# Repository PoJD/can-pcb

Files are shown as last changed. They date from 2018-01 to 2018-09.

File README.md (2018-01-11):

# can-pcb
Custom PCBs to be used for CAN bus in my home automation project
This repository contains 2 separate Eagle projects (http://www.cadsoftusa.com/) for custom PCB designed by myself to allow home automation system work with CAN BUS.

The basic idee is that there are 2 projects:

1. CanRelay
2. CanSwitch

CanRelay is a PCB that will be directly connected to the SSR relays and will consume traffic over the CAN bus (from either the webapp - hawa - or from CanSwitch) and translate that to switching output pins on that board's chip on or off. The board chip is PIC18F25K80 and is programmed through either CanRelay.X or CanSwitch.X mplab projects here: https://github.com/PoJD/can

CanSwitch is a PCB that will be present in the wall and would have 1 single input for the input switch, 1 single output for an indicator LED and would be connected to the CAN network too and transfer the toggle switch CAN messages over the wire to the CanRelay PCB to process.

Followed https://www.sparkfun.com/tutorials/110 to create custom components bought for this PCB and resulting in a custom library here: https://github.com/PoJD/eagle
Then followed https://learn.sparkfun.com/tutorials/using-eagle-schematic/adding-parts-to-a-schematic and other related guides to create the PCB in Eagle application.

https://learn.sparkfun.com/tutorials/using-eagle-board-layout#generating-gerbers and http://www.allpcb.com/sns/Gerber+File/2017-02-24_1_10_4819_Create+a+Gerber+File+with+Eagle/rpllst.html for generating Gerber files to let the PCBs get manufactured

See details of the communication protocal in that project, this is simply a project designed to have custom boards that would then be installed in the house.

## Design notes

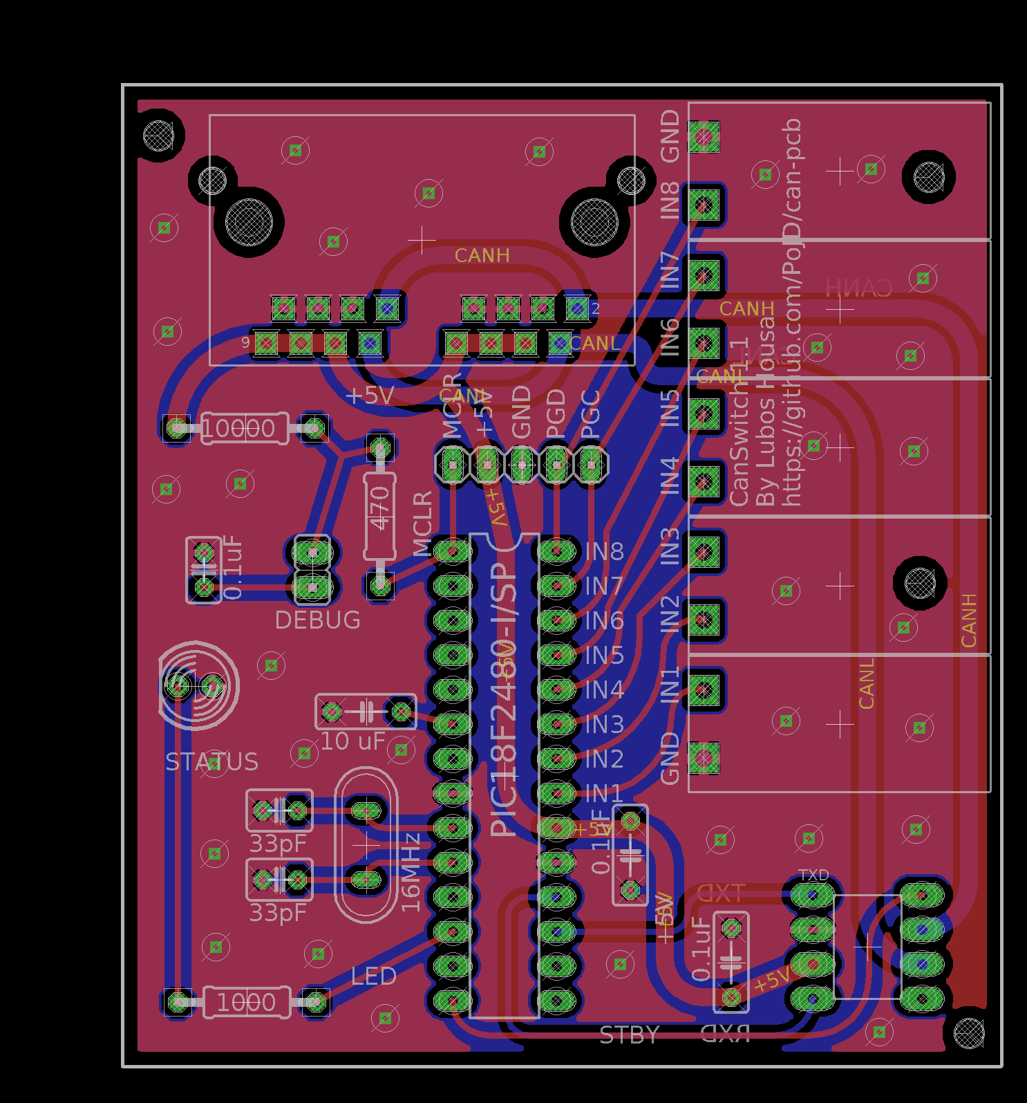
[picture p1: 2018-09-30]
Gerbers/CanSwitch/ImageExport.png

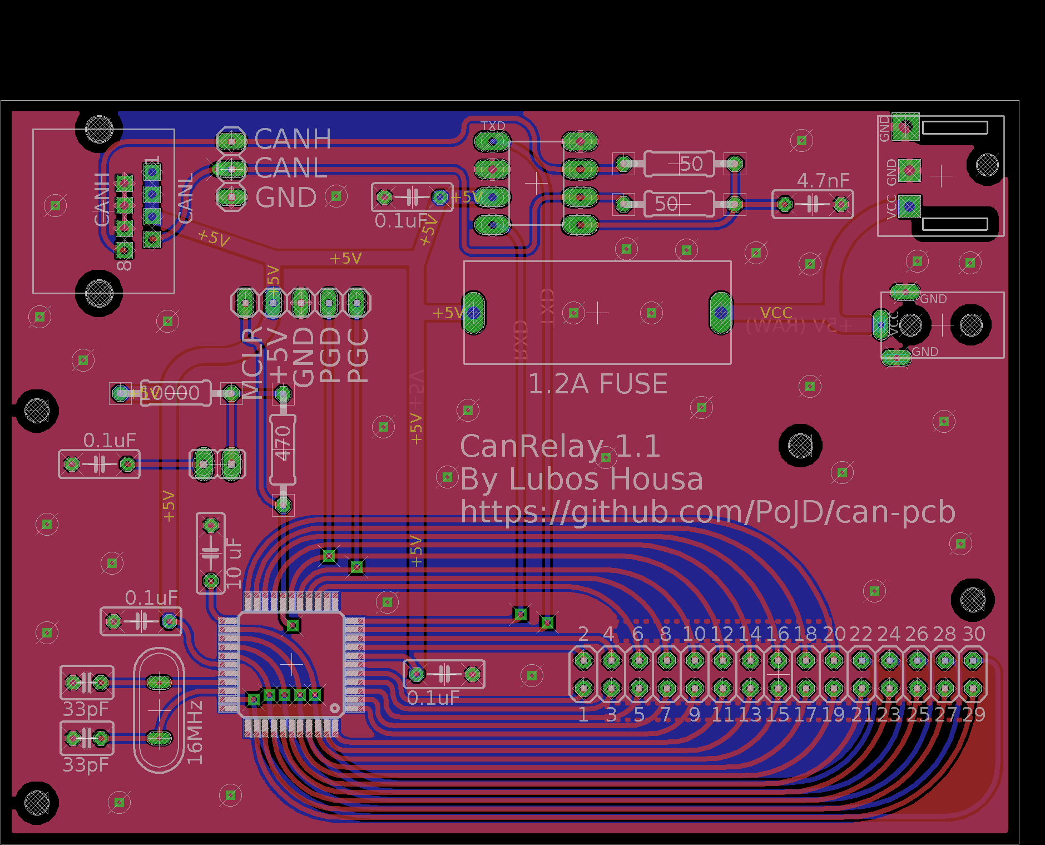
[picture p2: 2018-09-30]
Gerbers/CanRelay/ImageExport.png

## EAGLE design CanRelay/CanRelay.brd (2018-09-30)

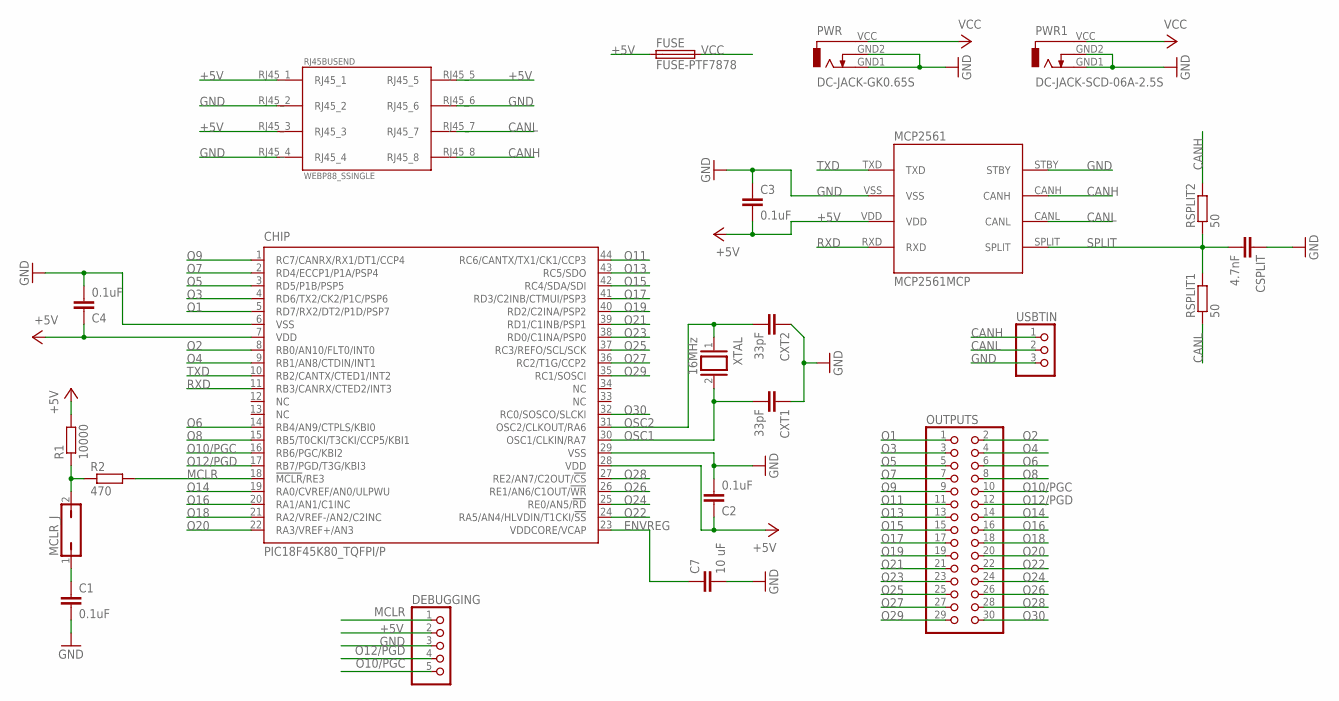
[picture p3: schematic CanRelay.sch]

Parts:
C1, C2, C3, C4: 0.1uF; C050-025X075
C7: 10 uF; C050-025X075
CHIP: PIC18F45K80_TQFPI/P; TQFP44
CSPLIT: 4.7nF; C050-025X075
CXT1, CXT2: 33pF; C025-030X050
DEBUGGING: PINHD-1X5; 1X05
FUSE: FUSE-PTF7878; FUSE-PTF78
MCLR_J: JP1Q; JP1
MCP2561: MCP2561MCP; MCP2561_PDIP
OUTPUTS: PINHD-2X15; 2X15
PWR: DC-JACK-GK0.65S; DC-JACK-GK0.65
PWR1: DC-JACK-SCD-06A-2.5S; DC-JACK-SCD-016A-2.5
R1: 10000; 0207/10
R2: 470; 0207/10
RJ45BUSEND: WEBP88_SSINGLE; WEBP88_RJ45_SINGLE
RSPLIT1, RSPLIT2: 50; 0207/10
USBTIN: PINHD-1X3; 1X03
XTAL: 16MHz; QS

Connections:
+5V: C2.1, C3.2, C4.1, CHIP.7 (VDD), CHIP.28 (VDD), DEBUGGING.2, FUSE.P1 (1), MCP2561.VDD, R1.2, RJ45BUSEND.RJ45_1, RJ45BUSEND.RJ45_3, RJ45BUSEND.RJ45_5
CANH: MCP2561.CANH, RJ45BUSEND.RJ45_8, RSPLIT2.2, USBTIN.1
CANL: MCP2561.CANL, RJ45BUSEND.RJ45_7, RSPLIT1.1, USBTIN.2
ENVREG: C7.1, CHIP.23 (VDDCORE/VCAP)
GND: C1.2, C2.2, C3.1, C4.2, C7.2, CHIP.6 (VSS), CHIP.29 (VSS), CSPLIT.1, CXT1.1, CXT2.1, DEBUGGING.3, MCP2561.STBY, MCP2561.VSS, PWR.GND1, PWR.GND2, PWR1.GND1, PWR1.GND2, RJ45BUSEND.RJ45_2, RJ45BUSEND.RJ45_4, RJ45BUSEND.RJ45_6, USBTIN.3
MCLR: CHIP.18 (!MCLR!/RE3), DEBUGGING.1, R2.2
unnamed: C1.1, MCLR_J.1
unnamed: MCLR_J.2, R1.1, R2.1
O1: CHIP.5 (RD7/RX2/DT2/P1D/PSP7), OUTPUTS.1
O2: CHIP.8 (RB0/AN10/FLT0/INT0), OUTPUTS.2
O3: CHIP.4 (RD6/TX2/CK2/P1C/PSP6), OUTPUTS.3
O4: CHIP.9 (RB1/AN8/CTDIN/INT1), OUTPUTS.4
O5: CHIP.3 (RD5/P1B/PSP5), OUTPUTS.5
O6: CHIP.14 (RB4/AN9/CTPLS/KBI0), OUTPUTS.6
O7: CHIP.2 (RD4/ECCP1/P1A/PSP4), OUTPUTS.7
O8: CHIP.15 (RB5/T0CKI/T3CKI/CCP5/KBI1), OUTPUTS.8
O9: CHIP.1 (RC7/CANRX/RX1/DT1/CCP4), OUTPUTS.9
O10/PGC: CHIP.16 (RB6/PGC/KBI2), DEBUGGING.5, OUTPUTS.10
O11: CHIP.44 (RC6/CANTX/TX1/CK1/CCP3), OUTPUTS.11
O12/PGD: CHIP.17 (RB7/PGD/T3G/KBI3), DEBUGGING.4, OUTPUTS.12
O13: CHIP.43 (RC5/SDO), OUTPUTS.13
O14: CHIP.19 (RA0/CVREF/AN0/ULPWU), OUTPUTS.14
O15: CHIP.42 (RC4/SDA/SDI), OUTPUTS.15
O16: CHIP.20 (RA1/AN1/C1INC), OUTPUTS.16
O17: CHIP.41 (RD3/C2INB/CTMUI/PSP3), OUTPUTS.17
O18: CHIP.21 (RA2/VREF-/AN2/C2INC), OUTPUTS.18
O19: CHIP.40 (RD2/C2INA/PSP2), OUTPUTS.19
O20: CHIP.22 (RA3/VREF+/AN3), OUTPUTS.20
O21: CHIP.39 (RD1/C1INB/PSP1), OUTPUTS.21
O22: CHIP.24 (RA5/AN4/HLVDIN/T1CKI/!SS!), OUTPUTS.22
O23: CHIP.38 (RD0/C1INA/PSP0), OUTPUTS.23
O24: CHIP.25 (RE0/AN5/!RD!), OUTPUTS.24
O25: CHIP.37 (RC3/REFO/SCL/SCK), OUTPUTS.25
O26: CHIP.26 (RE1/AN6/C1OUT/!WR!), OUTPUTS.26
O27: CHIP.36 (RC2/T1G/CCP2), OUTPUTS.27
O28: CHIP.27 (RE2/AN7/C2OUT/!CS!), OUTPUTS.28
O29: CHIP.35 (RC1/SOSCI), OUTPUTS.29
O30: CHIP.32 (RC0/SOSCO/SLCKI), OUTPUTS.30
OSC1: CHIP.30 (OSC1/CLKIN/RA7), CXT1.2, XTAL.2
OSC2: CHIP.31 (OSC2/CLKOUT/RA6), CXT2.2, XTAL.1
RXD: CHIP.11 (RB3/CANRX/CTED2/INT3), MCP2561.RXD
SPLIT: CSPLIT.2, MCP2561.SPLIT, RSPLIT1.2, RSPLIT2.1
TXD: CHIP.10 (RB2/CANTX/CTED1/INT2), MCP2561.TXD
VCC: FUSE.P2 (2), PWR.VCC, PWR1.VCC

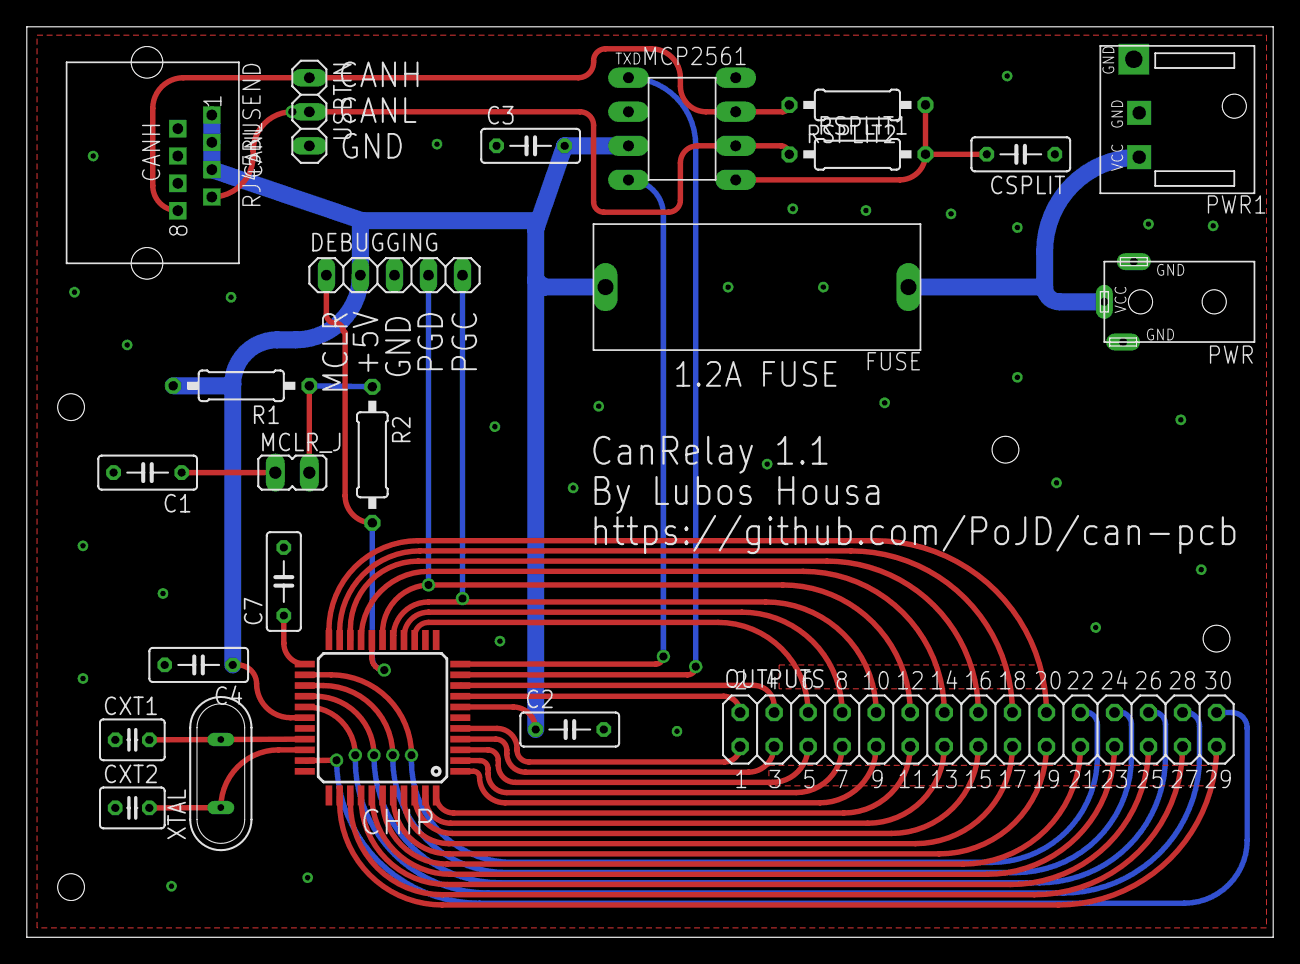
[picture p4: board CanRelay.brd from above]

Board: 2 copper layers, 93.0 x 67.9 mm, 23 parts (0 on the bottom side), 44 nets.

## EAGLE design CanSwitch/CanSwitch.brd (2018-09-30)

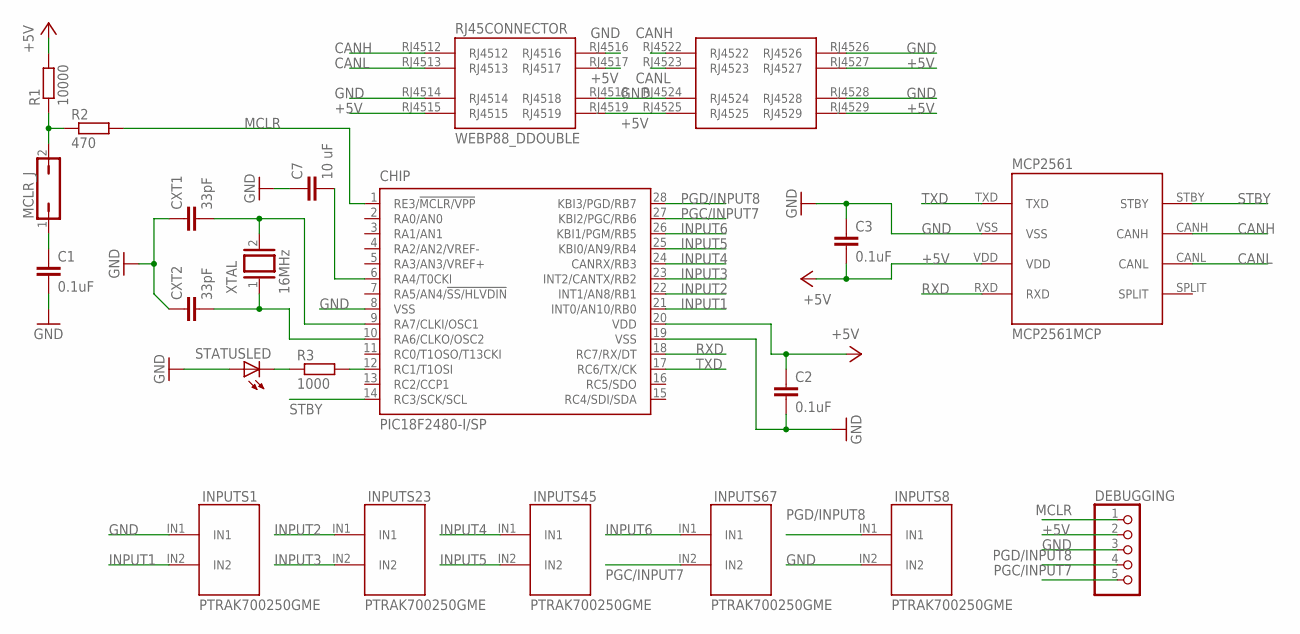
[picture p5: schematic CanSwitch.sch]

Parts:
C1: 0.1uF; C025-025X050
C2, C3: 0.1uF; C050-025X075
C7: 10 uF; C050-025X075
CHIP: PIC18F2480-I/SP; DIL28-3
CXT1, CXT2: 33pF; C025-030X050
DEBUGGING: PINHD-1X5; 1X05
INPUTS1, INPUTS8, INPUTS23, INPUTS45, INPUTS67: PTRAK700250GME; PTR_AK700_2_5.0
MCLR_J: JP1Q; JP1
MCP2561: MCP2561MCP; MCP2561_PDIP
R1: 10000; 0207/10
R2: 470; 0207/10
R3: 1000; 0207/10
RJ45CONNECTOR: WEBP88_DDOUBLE; WEBP88_RJ45_DOUBLE
STATUSLED: LED5MM
XTAL: 16MHz; QS

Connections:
+5V: C2.1, C3.2, CHIP.20 (VDD), DEBUGGING.2, MCP2561.VDD, R1.2, RJ45CONNECTOR.RJ4515, RJ45CONNECTOR.RJ4517, RJ45CONNECTOR.RJ4519, RJ45CONNECTOR.RJ4525, RJ45CONNECTOR.RJ4527, RJ45CONNECTOR.RJ4529
CANH: MCP2561.CANH, RJ45CONNECTOR.RJ4512, RJ45CONNECTOR.RJ4522
CANL: MCP2561.CANL, RJ45CONNECTOR.RJ4513, RJ45CONNECTOR.RJ4523
GND: C1.2, C2.2, C3.1, C7.1, CHIP.8 (VSS), CHIP.19 (VSS), CXT1.1, CXT2.1, DEBUGGING.3, INPUTS1.IN1, INPUTS8.IN2, MCP2561.VSS, RJ45CONNECTOR.RJ4514, RJ45CONNECTOR.RJ4516, RJ45CONNECTOR.RJ4518, RJ45CONNECTOR.RJ4524, RJ45CONNECTOR.RJ4526, RJ45CONNECTOR.RJ4528, STATUSLED.A
INPUT1: CHIP.21 (INT0/AN10/RB0), INPUTS1.IN2
INPUT2: CHIP.22 (INT1/AN8/RB1), INPUTS23.IN1
INPUT3: CHIP.23 (INT2/CANTX/RB2), INPUTS23.IN2
INPUT4: CHIP.24 (CANRX/RB3), INPUTS45.IN1
INPUT5: CHIP.25 (KBI0/AN9/RB4), INPUTS45.IN2
INPUT6: CHIP.26 (KBI1/PGM/RB5), INPUTS67.IN1
MCLR: CHIP.1 (RE3/!MCLR/VPP), DEBUGGING.1, R2.2
unnamed: C1.1, MCLR_J.1
unnamed: MCLR_J.2, R1.1, R2.1
unnamed: C7.2, CHIP.6 (RA4/T0CKI)
unnamed: CHIP.12 (RC1/T1OSI), R3.2
unnamed: R3.1, STATUSLED.K (C)
OSC1: CHIP.9 (RA7/CLKI/OSC1), CXT1.2, XTAL.2
OSC2: CHIP.10 (RA6/CLKO/OSC2), CXT2.2, XTAL.1
PGC/INPUT7: CHIP.27 (KBI2/PGC/RB6), DEBUGGING.5, INPUTS67.IN2
PGD/INPUT8: CHIP.28 (KBI3/PGD/RB7), DEBUGGING.4, INPUTS8.IN1
RXD: CHIP.18 (RC7/RX/DT), MCP2561.RXD
STBY: CHIP.14 (RC3/SCK/SCL), MCP2561.STBY
TXD: CHIP.17 (RC6/TX/CK), MCP2561.TXD

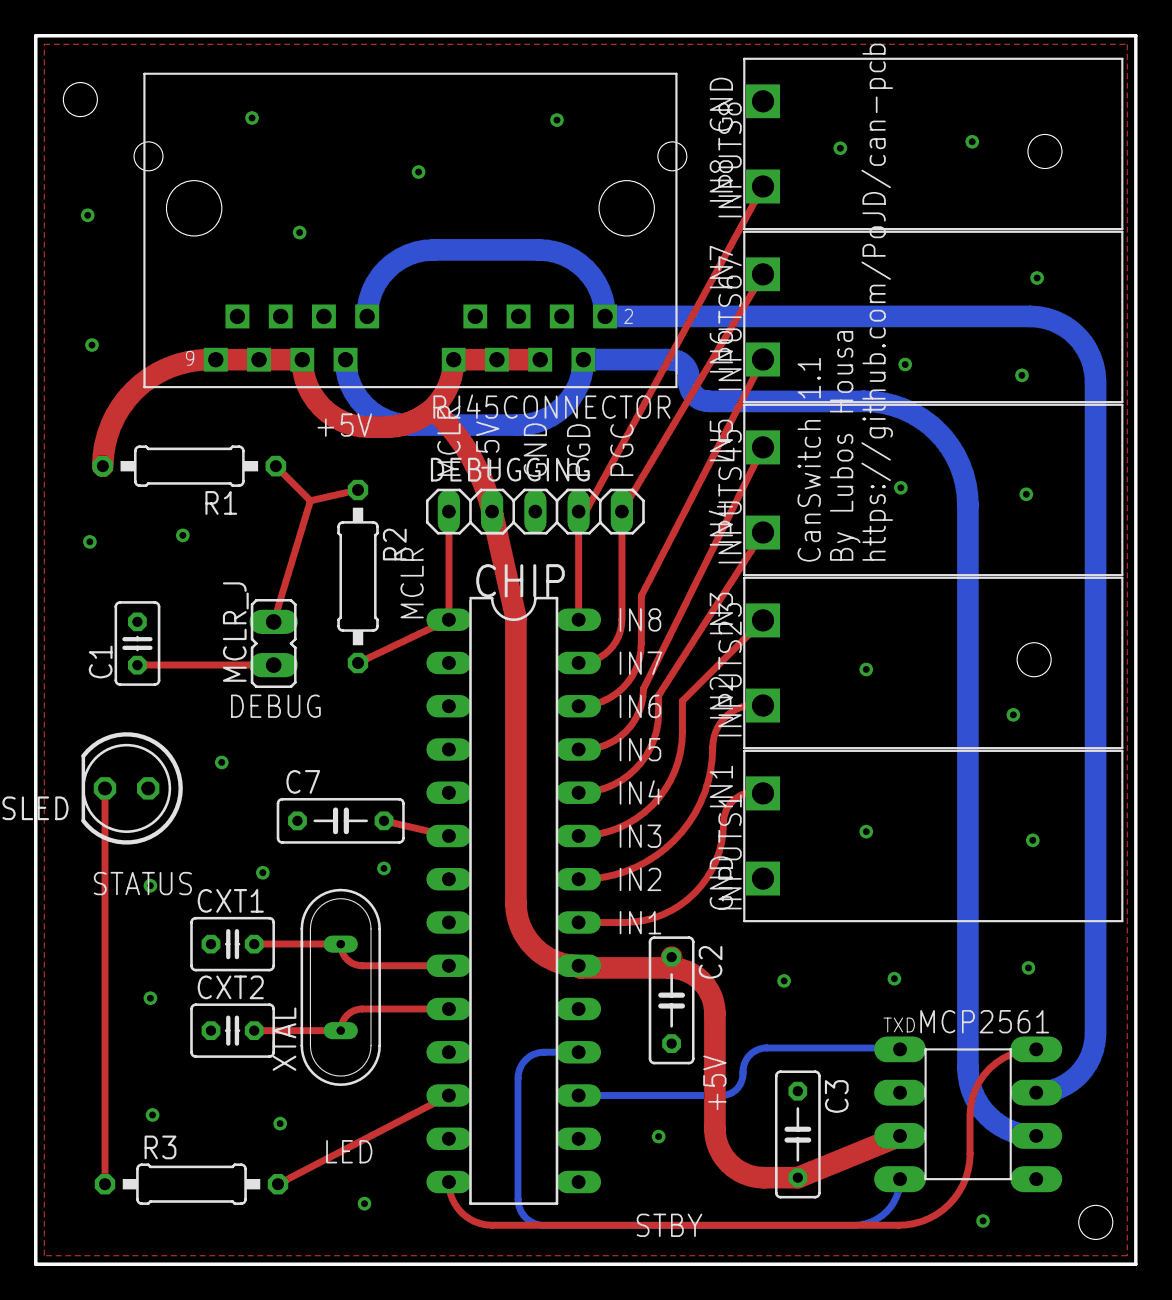
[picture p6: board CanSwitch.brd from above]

Board: 2 copper layers, 64.6 x 72.1 mm, 21 parts (0 on the bottom side), 23 nets.

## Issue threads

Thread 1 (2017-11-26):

Review XTAL ground copper and add to eagle project

PoJD, 2017-11-26:
Page 49/622 in datasheet talks about it in more detail

PoJD, 2017-12-29:
Fixed

Closed 2017-12-29.

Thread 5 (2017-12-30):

New components needed for CanRelay schema and board

PoJD, 2017-12-30:
- [x] - https://www.gme.cz/rj-konektor-webp-8-8-pcb - single RJ45 plug
- [x] - https://www.gme.cz/ark350-3-blue - 3pin connector for usbtin
- [ ] - https://www.gme.cz/napajeci-souosy-konektor-pc-gk0-65  - power adapter (hopefully correct this time round)

Closed 2018-01-02.

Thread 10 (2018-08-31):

Fix CanRelay jack connector

PoJD, 2018-08-31:
Mirror the pins and use additional 2 for GND and 2 for PWR. And update schematic desc to use custom CAT5 wiring so that PWR is always twisted with GND, the same for CANH and CANL (already the case)

PoJD, 2018-09-16:
sizes shall be OK, checking datasheet of new power jack, need to double check at home the adapter only to be sure

Closed 2018-09-16.

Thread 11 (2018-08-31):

Fix CanSwitch jack connectors

PoJD, 2018-08-31:
Use unused pins for PWR and GND, match CanRelay, so that the same twisted pairs exist and are connected

Closed 2018-09-09.

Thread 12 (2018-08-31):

Additional power socket in CanRelay

PoJD, 2018-08-31:
so that we can connect the power and ground from the end points (CanRelays) to have the biggest consumers the closest to the power source so that the current has the shortest path to the most draining parts and rest of the power line therefore shall not see that much voltage drop.

PoJD, 2018-08-31:
check GME for parts as the one we have now does not seem to have suitable cables like the adapters I bought

PoJD, 2018-09-09:
https://www.gme.cz/napajeci-souosy-konektor-pc-gk2-1 i.e. https://www.gme.cz/data/attachments/dsh.806-312.1.pdf

PoJD, 2018-09-14:
Put two on each board in the end. The main relay would have all 3 soldered. One could go to another relay and the other one to SSR to give that juice. One 8channel SSR is said to draw 160mA max when all channels are ON. So even all 5 SSRs with 40 ports would still draw 800mA max and I will unlikely use all of them anyway. So should be good to power all up from 1 adapter then.

PoJD, 2018-09-14:
But best to measure SSR current drawn. And also the power adapter I already have - need to check it’s max current.

PoJD, 2018-09-14:
The main power jack has no current limit. So shall be fine after all.

PoJD, 2018-09-14:
Power adapter itself has 2A max. So ok too.

PoJD, 2018-09-15:
the 2.5mm jack has 0.5A limit though, but hopefully OK too or alternatively I can power it all up separately

Closed 2018-09-15.

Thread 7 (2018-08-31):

Support power sockets in canSwitches too

PoJD, 2018-08-31:
May become handy if voltage drops between relays is too high, calculate the voltage drops. At home with 4 nodes and roughly 15m CAT5 cable, first node had 5.1V, while the last one had 5.0V only, i.e. 0.1V drop across 15m. So over 90m I would get down to 4.5 only, which is absolute minimum.

PoJD, 2018-08-31:
For sure use unconnected wires for +5V and GND to decrease the voltage drop

PoJD, 2018-08-31:
Also implementing low power mode in canSwitches would indeed help

PoJD, 2018-08-31:
but first of all check whether we can connect multiple power sources like this

PoJD, 2018-08-31:
closing, will not do. No point in multiple power sources, not an issue of not enough power, need to sort out the voltage drop primarilly

PoJD, 2018-09-01:
So for voltages drop we have 0.188Ohm/m for CAT5. That is 37.6Ohm for 200m anticipated max length of the bus. For 1 wire only. If we run 3 wires PWR and GND, that would be just 12.53Ohm for that length. If we have power source at 5.1V and want to avoid going under 4.6, that gives max voltage drop of 0.5V. That means max current drawn from the line has to be 40mA

Closed 2018-08-31.

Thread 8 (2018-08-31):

CanSwitch PCB to support up to 8 independent inputs

PoJD, 2018-08-31:
Now it has just 1. Also put another RJ45 socket on the board for the additional switches. Even for 1. So that it snaps to the PCB and just the other side is using single wire connected.

PoJD, 2018-09-06:
RB2 and RB3 cannot be used since these are used as CANRX and CANTX

PoJD, 2018-09-09:
PGC and PGD are at the same time inputs and programming pins. so while programming, caution needs to be taken since this can also cause some lights to switch on

PoJD, 2018-09-09:
https://github.com/PoJD/can/issues/34 raised to compensate for some other changes in the board

PoJD, 2018-09-09:
In the end CAN RX and TX pins moved to RC, see the other ticket. So as a result we can use all B pins as inputs.

PoJD, 2018-09-09:
need to fix the clerance in the new RJ45 connector

Closed 2018-09-10.

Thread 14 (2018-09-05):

Switch debounce capacitors for all input pins

PoJD, 2018-09-05:
without this a lot of spurious triggers happen

PoJD, 2018-09-06:
investigate whether we can just connect some C and B ports to use schmitt trigger input on C and interrupts on B. 6 C ports should be free (2 are used by oscilator). perhaps try just 1 and connect it to B0 with a wire and configure as input and enable schmitt.

PoJD, 2018-09-06:
red herring, B ports shall be schmitt too, but still some debounce is observed. perhaps the switches themselves

Closed 2018-09-09.

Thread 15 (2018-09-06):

test all input pins fire

PoJD, 2018-09-06:
stress testing. wire up all input pins of all can switches together to be able to simulate all switches at once. observe the current drawn.

PoJD, 2018-10-29:
moved to can#48

Closed 2018-10-29.

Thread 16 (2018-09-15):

Fuse 2A?

PoJD, 2018-09-15:
2A or perhaps even just 1A to protect the circuit and power adapter from blowing. Perhaps optional on CanRelay. Somehow make it optional via a jumper so that only one relay will actually have it. Also buy it front GME then.

PoJD, 2018-09-16:
1.25A will be bought in the end. Not optional, but mandatory to make sure CanRelay as power source always protects the VDD supply to the line

Closed 2018-09-16.

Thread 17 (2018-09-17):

Replace RJ45 in CanSwitch with something better

PoJD, 2018-09-17:
Since running CAT5 to individual light switches would be a nightmare. Use something from this for example: https://www.gme.cz/nasuvne-vidlice-zasuvky-do-dps?price=1;354&tech_par[172][]=8061&showFilter=172&page=1#products perhaps in time with a wire secure like https://www.gme.cz/kabelova-prichytka-samolepici-kss-10j-s-14mm

Shoot for 9 pins so that we can eventually connect all 8 input pins + GND. Rename wiring accordingly in CanSwitch then.

PoJD, 2018-09-18:
or perhaps instead try buying new cable and test the connection out on some real switch

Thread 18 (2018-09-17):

test out CanRelay outputs connector

PoJD, 2018-09-17:
wire up the connector to the cable and test I can easilly plug it in, otherwise I may need to change this component on Relay too.

Closed 2018-09-18.

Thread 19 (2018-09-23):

Replace chip on CanRelay with SMD variant with 44pins

PoJD, 2018-09-23:
so that I can increase the output count from current 19 to up to 30 (35 minus CAN minus xtal minus MCLR - that can also be used as RE3 input only pin)

PoJD, 2018-09-25:
Also use this 2x15 for outputs: https://www.gme.cz/dutinkova-lista-bl8230g

PoJD, 2018-09-27:
in the end used https://www.gme.cz/oboustranny-kolik-ass23023g for outputs afterall. But the same design on PCB, just better to attach the connector to this

PoJD, 2018-09-28:
Missing now: avoid the new antenna fingers, add labels

Closed 2018-09-28.

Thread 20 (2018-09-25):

Better XTAL ground copper

PoJD, 2018-09-25:
Think over better ground for XTAL

PoJD, 2018-09-28:
End at the end also add missing ground cias in relay board

Closed 2018-09-28.

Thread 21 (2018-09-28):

Confirm small components lead width

PoJD, 2018-09-28:
At times it seems the resistors at least have too much space around them in PCB causing the soldier to run through. Check data sheets for both resistors and capacitors and other components and confirm/adjust the lead width

PoJD, 2018-09-28:
male pinhead seem to have 0.64 hole as opposed to 1 in all packages I checked so far.
Similarly capacitors seem to have 0.5 instead of 0.8 for all I have bought so far.
XTAL has 0.43mm.
R has 0.56mm.

PoJD, 2018-09-28:
https://electronics.stackexchange.com/questions/85292/what-pad-hole-drill-size-is-appropriate-for-a-given-through-hole-lead-diameter has a nice way to fit the hole sizes. I have all chips through hole and transceiver already confirmed as fine, so confirm the rest

PoJD, 2018-09-28:
Seems even transceiver and chip may be worth checking?

PoJD, 2018-09-29:
Using 0.8 for pinhead, 0.7 for R, 0.6 for capacitors and 0.5 for XTAL (taking into account drill size tolerance of +-0.05 in all parts and some in PCB manufacturing process too.

PoJD, 2018-09-29:
transceiver and through hole chip both ranked down from 0.8 to 0.7

PoJD, 2018-09-30:
Chip and transceiver through hole actually should use the original 0.8 since the leads are not round but rather rectangular. The diagonal is actually 0.67, so with the tolerance, 0.7 may end up being too small. So rather change these 2 back to original values.

Closed 2018-09-30.

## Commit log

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2016-04-10 added all component to schema, updated library before, missing capacitors and other basic resistors and connections
    [CanSwitch.sch]
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2017-02-26 wiring all up, done all in the switch with the exception of wiring up RJ45 to the rest
    [CanSwitch.sch]
2017-02-26 wired up all together, no resistor or capacitor added to switch board just yet, won't be here. Now can move to PCB
    [CanSwitch.sch]
2017-02-26 little edits to the schema - adding capacitors to each pair of VDD and VSS, creating first version of PCB. Missing box and proper wiring up
    [CanSwitch.brd, CanSwitch.sch]
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2017-11-26 cleanup after renaming libraries earlier this year and dropping auto routed nets in board to start from scratch again
    [CanSwitch.brd, CanSwitch.sch]
2017-11-26 rerouting all, moving debugger up close to the chip, all check passed now
    [CanSwitch.brd, CanSwitch.sch]
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2017-11-27 swapped proper package for capacitor and also updated library components and little tweaks to the wires
    [CanSwitch.brd, CanSwitch.sch]
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2017-12-30 #2 renamed few components, moved all to new origin, added holes for final drilling, added silkcreen to desc all, including signature. Not to print out names layers, only place and values layers in th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
    [CanSwitch.brd, CanSwitch.sch]
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2017-12-30 #1 dropping old polygons and replacing with full board ground polygons on both sides with isolation spacing 0.4
    [CanSwitch.brd]
2017-12-30 #3 deleted backup can switch board, added new can relay base schematic as a copy from can switch, only leaving common things in there
    [CanRelay.sch]
2017-12-30 #4 adding split pin and resistor termination to can bus as per datasheet. Plus adding all wires to the chip and naming them properly
    [CanRelay.sch]
2017-12-31 #5 added outputs 20pin header from built in library. Added all the wiring to it too, missing new components that need to be added
    [CanRelay.sch]
2018-01-01 #5 new component for RJ45 WEBPP single, also renamed old one to DOUBLE and updated CanSwitch project references, used in CanRelay now and added all the wiring to it too
    [CanRelay.sch, CanSwitch.brd, CanSwitch.sch]
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2018-01-01 #5 adding last missing component - power jack - to the schema only. And added all wiring, ready to generate the board now
    [CanRelay.sch]
2018-01-02 first test version of the board, playing around a bit with routing, just a first sketch layout of the components on the board
    [CanRelay.brd]
2018-01-02 first draft version of the board with routed everything and copper ground too
    [CanRelay.brd, CanRelay.sch, CanSwitch.brd]
2018-01-02 positioned all components nicely on the board and redid all wires thoroughly this time. Also replaced 3pin for usbtin by regular pinhead since that would be easier to plug into the board
    [CanRelay.brd, CanRelay.sch]
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2018-01-03 final tuning of both boards - squeezing switch board a bit yet, adding some more silkscreen, exporting to image to share on some electrical forums for checks
    [CanRelay.brd, CanRelay.sch, CanSwitch.brd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]
2018-01-04 incorporated hints from web: set proper sizes for caps, left enough space for them to be bend on the board. Reviewed any acute angles in traces. Increased isolation in ground copper so that no so cal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
    [CanRelay.brd, CanRelay.sch, CanSwitch.brd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]
2018-01-08 #6 added stitching vias to GND copper pour and some final little edits, dropping some values from some components not to spoil target PCB with extra text, checked text sizes and drill sizes, setup ER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
    [CanRelay.brd, CanRelay.sch, CanSwitch.brd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]
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2018-09-09 #11 fixing RJ45 connector - connecting unused pins to +5V and GND
    [CanSwitch.brd, CanSwitch.sch]
2018-09-09 #13 connect RC3 of chip and STBY of transceiver, no route yet in board until the new inputs are added
    [CanSwitch.brd, CanSwitch.sch]
2018-09-09 #8 support for 8 independent inputs - dropped old switch input and replaced with RJ45 connector - moved components around, moved transceiver down to the bottom and the new RJ45 in the middle close to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
    [CanSwitch.brd, CanSwitch.sch]
2018-09-10 #8 fine tuning RJ45 connections on the board - clearance errors fixed, moved components a tiny bit more, transceiver so that both CAN lines can be routed on the rights from the inputs and bottom laye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
    [CanSwitch.brd]
2018-09-13 #12 dropping 2 new power jacks into the schematic and connecting. Only dropping into the board, not yet aligning up all
    [CanRelay.brd, CanRelay.sch]
2018-09-15 #12 dropping the 2 and replacing with jut 1 new power jack, aliging all in board, not yet wiring all up since will need one more change to mirror the RJ45 connector anyway. but space now sufficient f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
    [CanRelay.brd, CanRelay.sch]
2018-09-15 #10 mirroring pins on RJ45 and wiring up remainder to +5V and GND in schematic. Started work in board - rewired all +5V in thicker wire everywhere. wired up RJ45 +5V and GND pins, CAN lines and RX an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
    [CanRelay.brd, CanRelay.sch]
2018-09-16 #10 rerouting unwired connections, moving old power jack a bit lower to have more space for the actual jack plug. routed TXD and RXD too. Missing checking all at home with the actual plug sizes, addi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
    [CanRelay.brd]
2018-09-16 #10 adding more missing GND vias to the board, running checks, adding missing labels in schematic, done #
    [CanRelay.brd, CanRelay.sch]
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2018-09-16 #16 adding new FUSE component - created before a new simple component from GME and added to schema now - wired up all, created new signal, used VCC for name and label +5V-RAW - this is the actual pow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
    [CanRelay.brd, CanRelay.sch]
2018-09-17 little tweaks on CanRelay - aligning more labels, adding new labels to bottom silk screen, adding more vias. ready for manufacturing!
    [CanRelay.brd]
2018-09-17 #12 fixing rectangle holes in new power connector to use dimension layer instead of rectangle in holes layer to assure these holes are really drilled
    [CanRelay.brd, CanRelay.sch]
2018-09-18 fine tuning can switch - adding labels to new inputs, increased spacing of top ground copper
    [CanSwitch.brd]
2018-09-18 final tweaks on CanRelay - moving CANH and CANL lines around transceiver as opposed to among its pads. Moved therefore 5V for transceiver to bottom layer. final tweaks of isolation of both ground pla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
    [CanRelay.brd]
2018-09-18 #17 replaced RJ45 for inputs with 5 PTR 2pins - RJ45 dropped and up to 5 individual PTR inputs I already bought added to the board so that they can be connected if needed - has the advantage of simpl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
    [CanRelay.brd, CanSwitch.brd, CanSwitch.sch]
2018-09-20 #17 fine tuning new input switches - added labels, updated few wires, ready to go
    [CanSwitch.brd]
2018-09-21 little tweaks of labels to be more visible on target board - just the DEBUGGING part
    [CanSwitch.brd]
2018-09-23 #19 dropped old chip, put new chip from eagle library on the schematic. put all mandatory connections to the chip so far only, so one more capacitor since this variant has 2 pairs of VSS and VDD pins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
    [CanRelay.brd, CanRelay.sch]
2018-09-24 #19 connected all but output ports, including RXD and TXD on both schema and the board, with no erc errors. Rotated the chip in the end to get MCLR and programming up and RX and TX closer to the tran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
    [CanRelay.brd, CanRelay.sch]
2018-09-26 #19 started connecting output ports. Bottom pat all done, also labeled properly, moved the whole PCB a few mms up to make space for routes there
    [CanRelay.brd, CanRelay.sch]
2018-09-27 #19 wired all up. Rewired bottom part a bit too to avoid clearance errors, rather more space down there. Also rewired +5V a bit close to MCLR resistor. Also routed RXD and TXD and PGC and PGD and cho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
    [CanRelay.brd, CanRelay.sch]
2018-09-28 #19 final changes after new chip - added labels to the output pinheader - added new cutout areas in top copper near the output pinheader to avoid ground copper antenna fingers in there - rewired MCLR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
    [CanRelay.brd]
2018-09-28 #20 XTAL copper is OK actually, makes no sense to isolate isolation around the pins anyway. So just added more GND vias and some new labels and moved FUSE label a bit too
    [CanRelay.brd]
2018-09-29 #21 decreasing drill size from 1 to 0.8 inline in all schema and boards for all pinhead components (debugging, usbtin and outputs in relay), so cannot now update all libraries anymore, but easier tha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
    [CanRelay.brd, CanRelay.sch, CanSwitch.brd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]
2018-09-29 #21 decreasing drill size from 0.8 to 0.7 inline in all schema and boards for all resistors
    [CanRelay.brd, CanRelay.sch, CanSwitch.brd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]
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2018-09-30 #21 reverting decrease in pad size for through hole transceiver and through hole chip in switch since it needs to be the original value in the end
    [CanRelay.brd, CanRelay.sch, CanSwitch.brd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]
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
